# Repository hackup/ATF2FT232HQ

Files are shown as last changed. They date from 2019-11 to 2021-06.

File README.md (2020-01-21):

# ATF1504-FT232HQ Shield

This is a "hat" PCB that plugs onto an easily available FT232H board and provides a JTAG interface to ATF1504 CPLDs. It allows those ICs to be programmed and even to be reset when their JTAG interface has been disabled. There is also no warranty whatsoever. **USE AT YOUR OWN RISK!**.

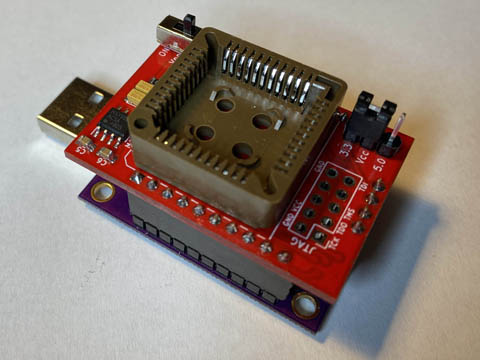
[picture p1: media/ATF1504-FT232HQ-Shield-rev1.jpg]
ATF1504-FT232HQ Shield Rev.1


See my [blog post](https://www.hackup.net/2020/01/erasing-and-programming-the-atf1504-cpld/) for more details.

## License


This work is licensed under a
[Creative Commons Attribution-NonCommercial-ShareAlike 4.0 International License](http://creativecommons.org/licenses/by-nc-sa/4.0/).

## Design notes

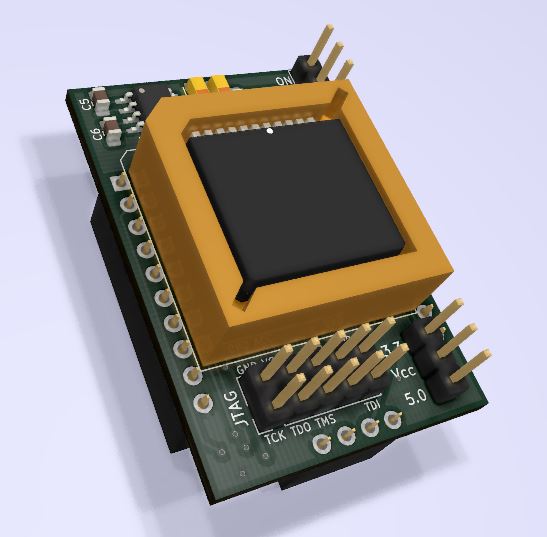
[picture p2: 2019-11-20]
media/atf2ft232hq-preview.JPG

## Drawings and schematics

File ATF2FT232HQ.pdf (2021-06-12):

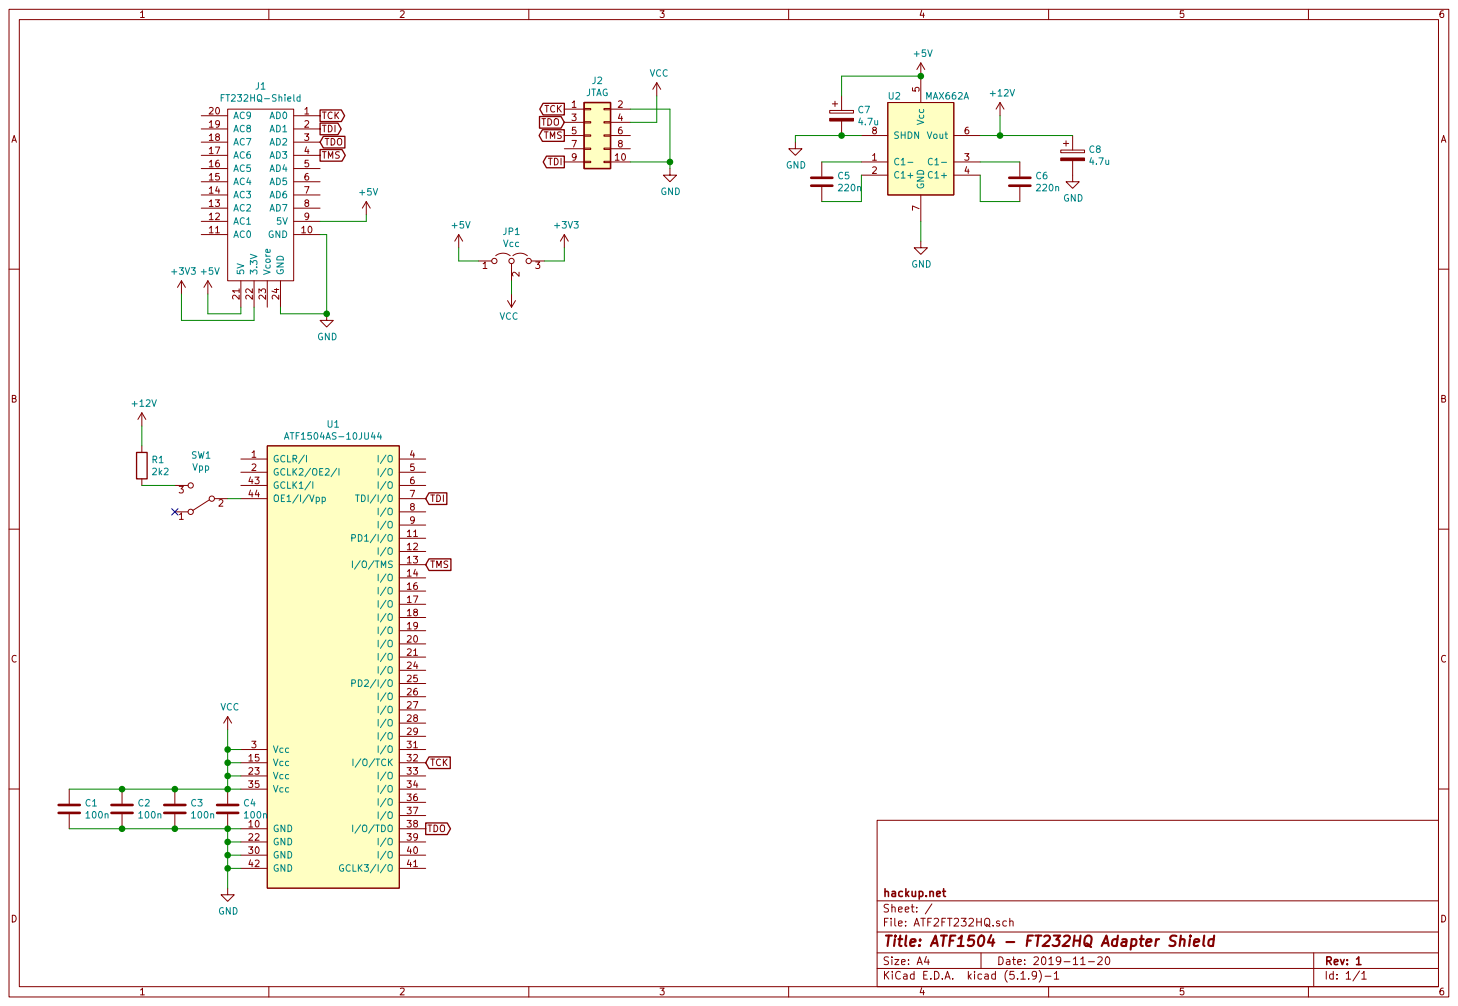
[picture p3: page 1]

File: ATF2FT232HQ.sch Sheet: / hackup.net

Id: 1/1 Title: ATF1504 - FT232HQ Adapter Shield

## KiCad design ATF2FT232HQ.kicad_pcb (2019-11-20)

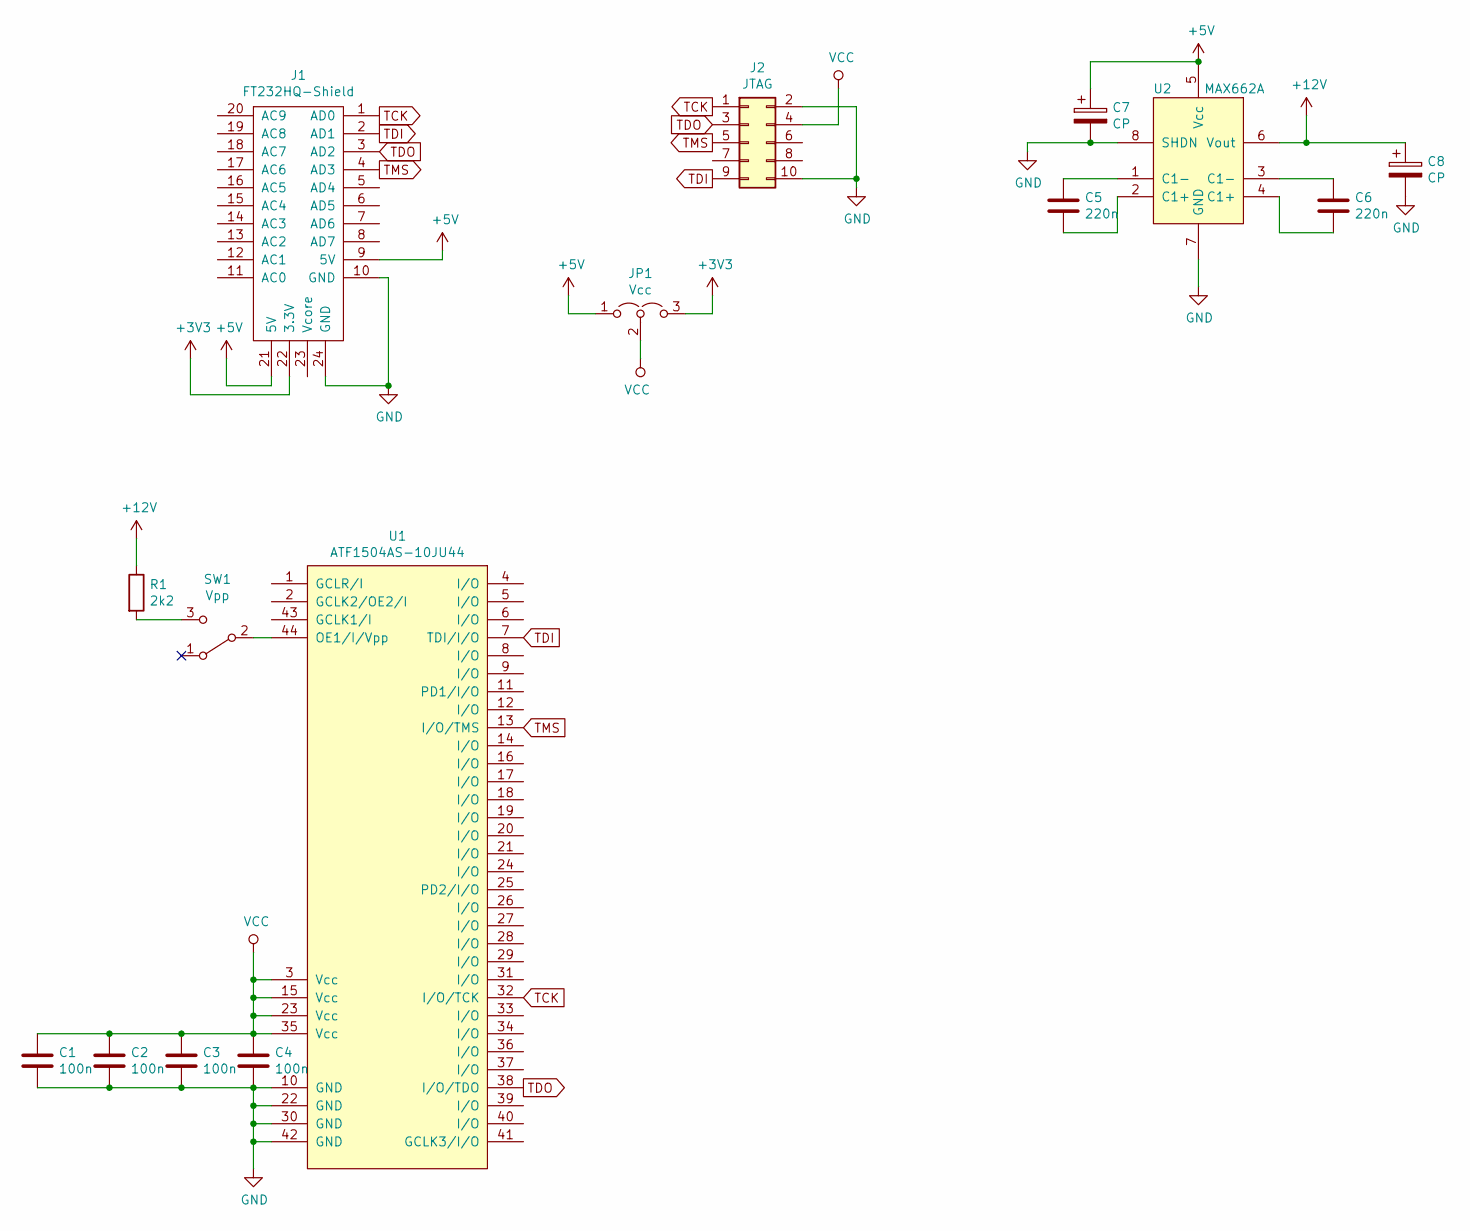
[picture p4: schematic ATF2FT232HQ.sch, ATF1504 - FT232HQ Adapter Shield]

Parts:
C1, C2, C3, C4: 100n; C_0805_2012Metric_Pad1.15x1.40mm_HandSolder
C5, C6: 220n; C_0805_2012Metric_Pad1.15x1.40mm_HandSolder
C7, C8: CP; CP_EIA-3216-18_Kemet-A_Pad1.58x1.35mm_HandSolder
J1: FT232HQ-Shield
J2: JTAG; PinHeader_2x05_P2.54mm_Vertical
JP1: Vcc; PinHeader_1x03_P2.54mm_Vertical
R1: 2k2; R_0805_2012Metric_Pad1.15x1.40mm_HandSolder
SW1: Vpp; PinHeader_1x03_P2.54mm_Vertical
U1: ATF1504AS-10JU44; PLCC-44_THT-Socket
U2: MAX662A; SOIC-8_3.9x4.9mm_P1.27mm

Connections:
+3V3: J1.22 (3.3V), JP1.3 (B)
+5V: C7.1, J1.9 (5V), J1.21 (5V), JP1.1 (A), U2.5 (Vcc)
+12V: C8.1, R1.1, U2.6 (Vout)
GND: C1.2, C2.2, C3.2, C4.2, C7.2, C8.2, J1.10 (GND), J1.24 (GND), J2.2, J2.10, U1.10 (GND), U1.22 (GND), U1.30 (GND), U1.42 (GND), U2.7 (GND), U2.8 (SHDN)
unnamed: C5.1, U2.1 (C1-)
unnamed: C5.2, U2.2 (C1+)
unnamed: C6.1, U2.3 (C1-)
unnamed: C6.2, U2.4 (C1+)
unnamed: R1.2, SW1.3 (C)
unnamed: SW1.2 (B), U1.44 (OE1/I/Vpp)
TCK: J1.1 (AD0), J2.1, U1.32 (I/O/TCK)
TDI: J1.2 (AD1), J2.9, U1.7 (TDI/I/O)
TDO: J1.3 (AD2), J2.3, U1.38 (I/O/TDO)
TMS: J1.4 (AD3), J2.5, U1.13 (I/O/TMS)
VCC: C1.1, C2.1, C3.1, C4.1, J2.4, JP1.2 (C), U1.3 (Vcc), U1.15 (Vcc), U1.23 (Vcc), U1.35 (Vcc)

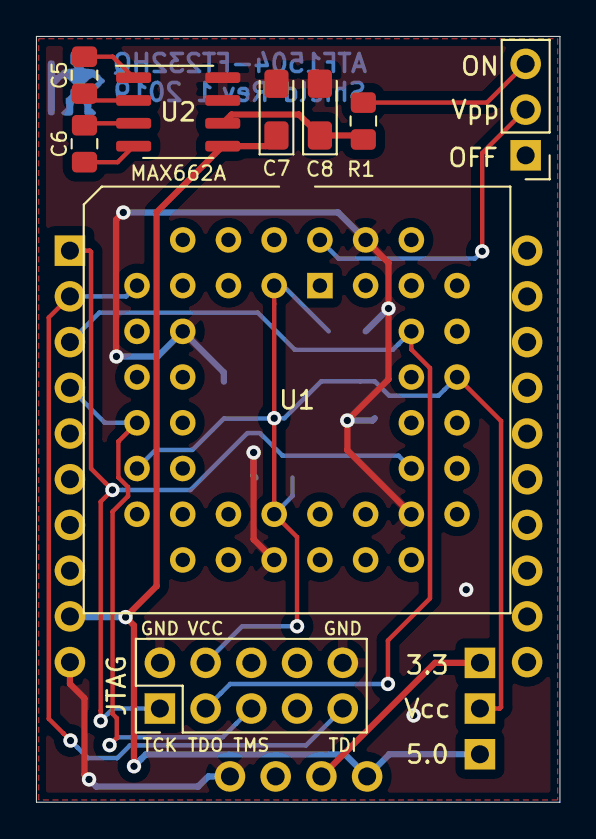
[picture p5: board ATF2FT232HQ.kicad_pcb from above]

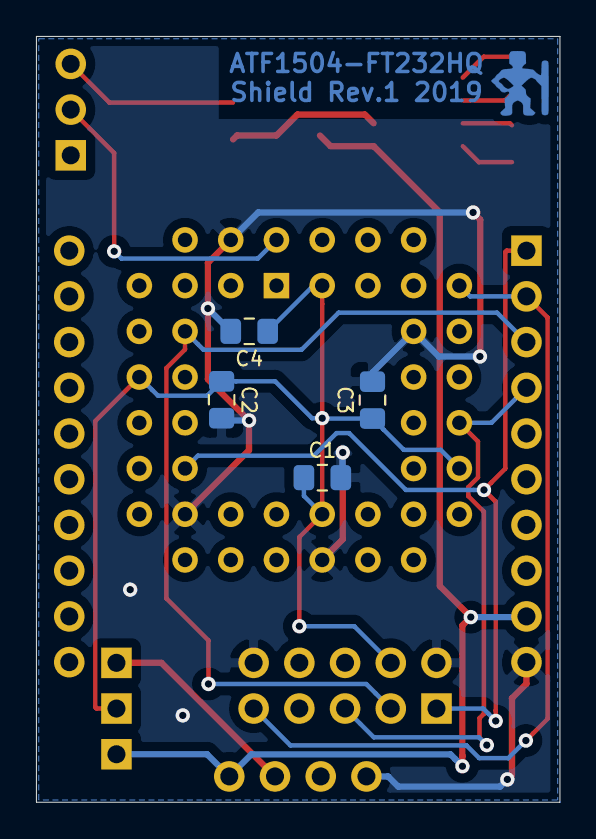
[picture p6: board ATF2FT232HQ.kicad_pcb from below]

Board: 2 copper layers, 29.1 x 42.5 mm, 15 parts (4 on the bottom side), 15 nets.

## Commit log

2019-11-19 Started routing.
    [ATF2FT232HQ.kicad_pcb, ATF2FT232HQ.sch]
2019-11-20 First routing completed.
    [ATF2FT232HQ.kicad_pcb, ATF2FT232HQ.sch]
2019-11-20 Moved components to the top.
    [ATF2FT232HQ.kicad_pcb, ATF2FT232HQ.sch]
2019-11-20 Labeled and tagged.
    [ATF2FT232HQ.kicad_pcb]
2019-11-20 Updated MAX662 footprint.
    [ATF2FT232HQ.kicad_pcb, ATF2FT232HQ.sch]
2019-11-20 Prepared Gerber export.
    [ATF2FT232HQ.kicad_pcb]
2020-01-21 Added readme and schematics.
2021-06-12 Fixed typo.
    [ATF2FT232HQ.sch]
